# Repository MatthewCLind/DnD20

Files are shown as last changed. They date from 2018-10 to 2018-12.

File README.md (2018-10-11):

# DnD20
WiFi Connected electronic die for enhancing online DnD gameplaying

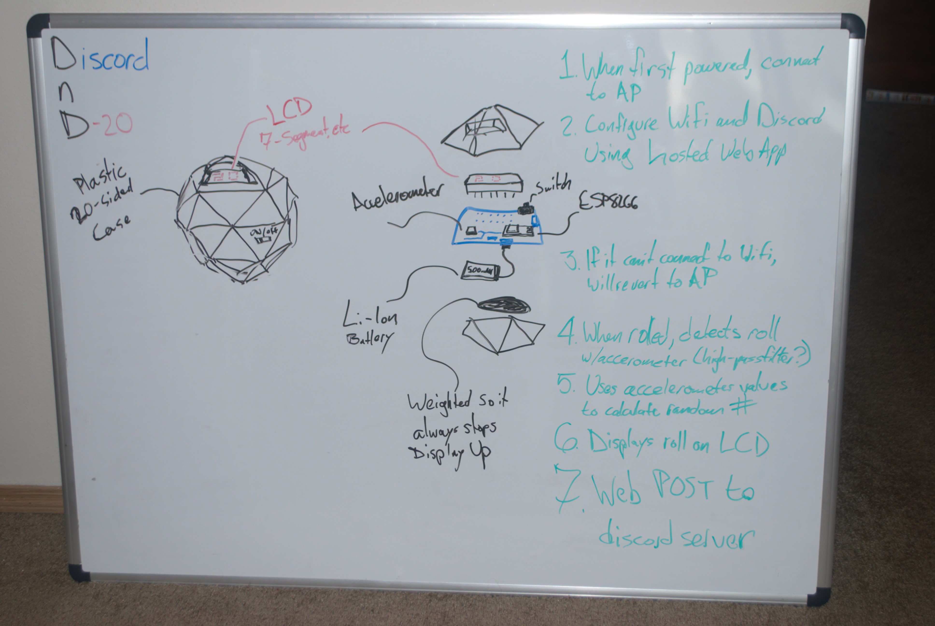
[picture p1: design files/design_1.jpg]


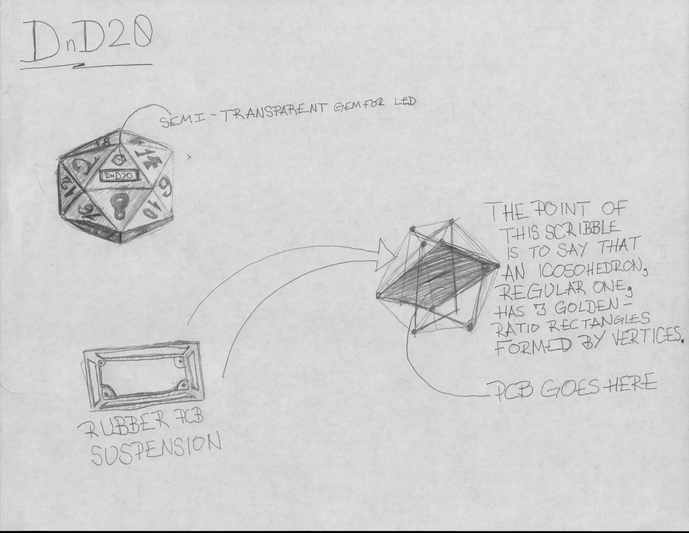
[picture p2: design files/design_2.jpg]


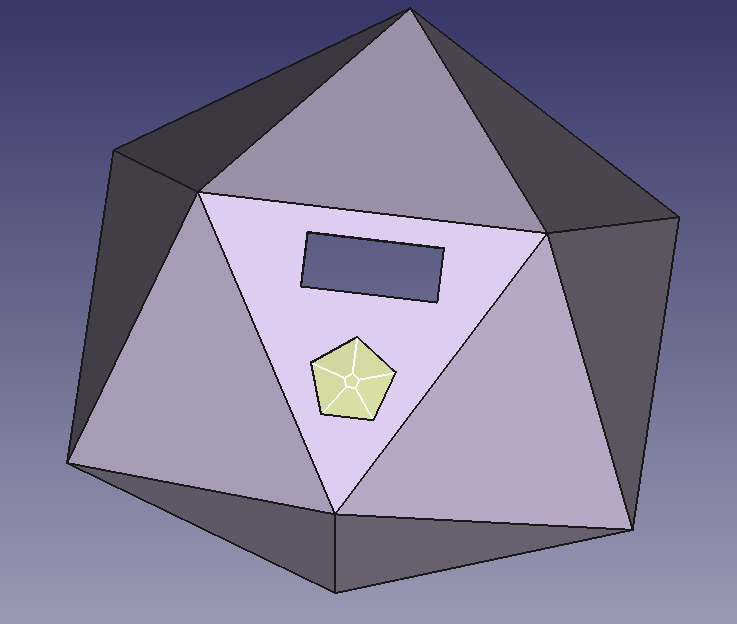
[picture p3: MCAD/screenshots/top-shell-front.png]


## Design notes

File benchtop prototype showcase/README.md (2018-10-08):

# Benchtop Prototype

**Rolling a Nat 20**

critical

### 1. Connect to WiFi

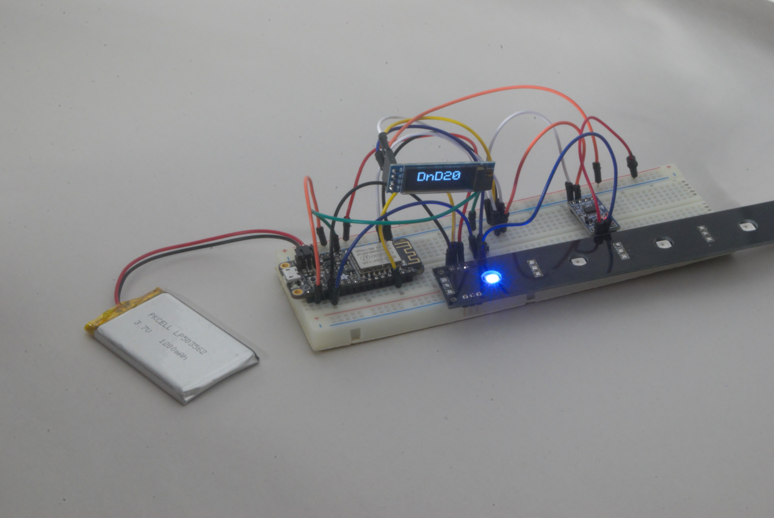
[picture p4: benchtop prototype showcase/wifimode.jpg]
wifi


When DnD20 first starts, the LED will be purple (it looks more purple IRL). This means that you are ready to enter in your WiFi credentials to get it logged on. 

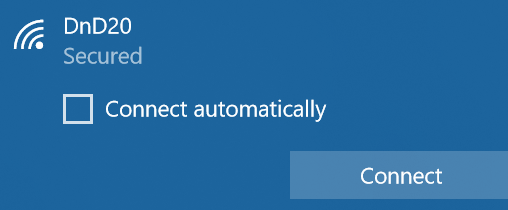
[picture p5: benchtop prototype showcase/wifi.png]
wifi


*the password is prestidigitation*

Alternatively, you can skip this step and start rolling without internet connection by pressing and holding the button.

In the future you'll be able to enter in your Discord server URL and a name for the bot, but for now you have to hardcode it in.

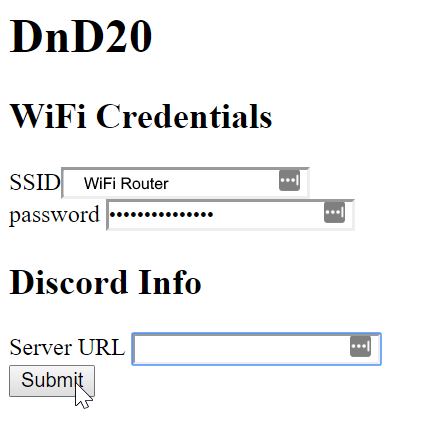
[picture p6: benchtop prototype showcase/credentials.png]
credentials


### 2. Start Rolling
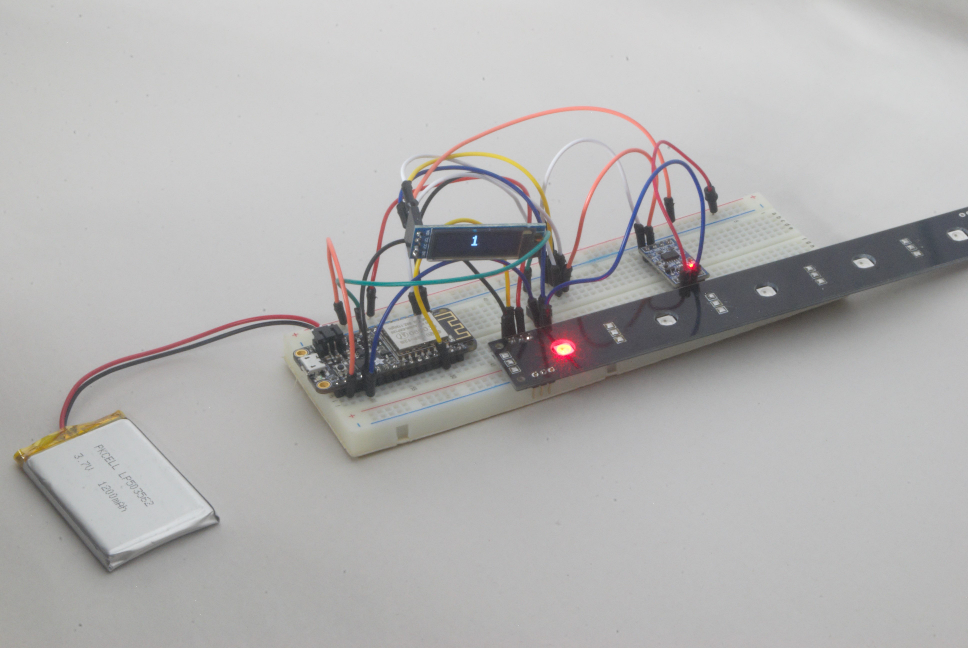
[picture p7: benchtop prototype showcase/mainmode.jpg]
failure


You can now start rolling a D20. Right now, rolling is simply tilting the device far enough toward the positive x direction for a moment. 

A Critical Failure turns the LED **red** in shame. A natural 20 turns the LED **gold** in triumph.

After rolling, there is a 10-second timeout so you can look at the device without re-rolling. To skip this, press the button momentarily.

If everything goes well with the WiFi setup and Discord webhook, and everything in-between, then your rolls should start showing up on your Discord server!

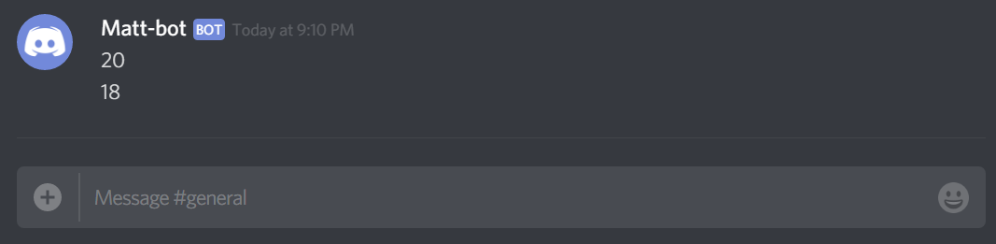
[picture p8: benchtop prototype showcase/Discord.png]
discord


### 3. Change the Die
program

While in the main rolling mode, you can change over to *Programming Mode* by pressing and holding the button.

In this mode, the LED turns green, and you can change the sidedness of the dice. So you can get anything from a d2 to a d20.

# What's Next?
Now that I've got everything working, at least when I'm lucky, it's time for improvements and upgrades.

### Code
The code is a mess. It is cobbled together. Re-organizing will help readability. I will also considering moving chunks to their own files.

The other most important thing is to get stability to the code. The ESP8266 still restarts occasionally, and has trouble advancing into the "normal mode". This has something to do with giving CPU time over to the WiFi duties by calling yield(). There may also be some strange conflicts in the libraries I'm using, since some of them are shared by multiple classes.

### Mechanical
I want to design the shell for this device. It will obviously be a d20. I'm imagining it in 2 halves. Where they come together will be a spot for the PCB. The button and power switch don't necessarily need to come off of the PCB itself, but can be attached with wires and be screwed into the side of the shell.

One thing I'm curious about is the placement of the accelerometer. It can either go near the middle or near the outside. Near the outside seems like it would hit the highest peak forces. The highest-acceleration would be from gravity and centripetal acceleration as the device rolls.

Placing the accelerometer in the center means that centripetal force is negligible. So all of the forces are from gravity only, and we'll just see the force vector moving around at a more constant magnitude. This might simplify the analysis it takes to determine a legitimate roll.

One more thing on the mechanical side. I was thinking the PCB might be put on rubber standoffs. I imagine a rubber net of sorts. The advantage to this is it acts like a low-pass filter. The device is going to be thrown on a table which will generate sharp peaks of force that could be a problem.

### Electronics
The next step here is to design a PCB. I mean, I could solder it up, but PCBs are so much nicer and more fun. The schematic can be done right away. The most uncertain part for me is the accelerometer board. The ESP8266 is an Adafruit Huzzah Feather board, so I can use their schematic to figure stuff out. The LED is a WS2812, which only needs a capacitor and maybe a resistor. As for the OLED, I'll probably just stick with the current screen.

I'm going to use this project as an opportunity to use the FreeCAD Stepup plugin to generate a board layer from an mCAD file.

### Functionality

**Programming Mode**
* I want to combine the WiFi setup with the program mode, it makes more sense to have a single programming mode
* Then, I want to have the Web App always hosted in programming mode. It will be accessible through the hosted Access Point if the WiFi isn't setup, or through the local network if it is connected
* The Web App will have more features, like being able to set the sidedness of the die, changing the Bot name, and the Discord server

**Magic 8-Ball**
* This thing is just asking to become a magic 8 ball, so I'll oblige
* Will be selectable through the web-app, or through some sort of button press, maybe holding for longer

**Button & LED**
* Right now you have to count in your head, then add some, to make sure you've held the button down long enough
* Instead, the LED should change colors once you've held the button down long enough, so you know you can let go. This also enables the use of holding down for long periods to cycle through several different options

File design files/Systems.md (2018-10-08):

/pulled from captain's log stardate-12018.10.4/

# Power
- li-ion battery powered
- needs to last 10 hours (5 hours of gameplay, plus 5 hours of "oops I forgot to charge this")
- On/Off switch to save power
- USB rechargeable
- Display
- Displays up to 99 (IE 2 digits)
- Backlit
- RGB LED
- Flashes heroically when a nat 20 is rolled
- Lights up triumphantly when denatured 20 is rolled
- Burns with sorrow when a critical failure is rolled

# Button Input
- One push button to cycle through type of die
- Push + hold for 3 seconds to enter programming mode
- Set it to D2, D3, ... , D99
- Display shows die type at boot

# Accelerometer
- Determines between roll and simply being moved about
    - How?
    - Band-pass filter?
    - Magnitude of force-vector?
    - Conic-volume traced out by force-vector > some amount?
    - Area of surface traced out by force-vector?
- Provides data to create random number

# WiFi
- At first provides access point for configuration
    * Ideally captive access point
    * Configuration = wifi credentials, Discord server config
- If wifi router access is unobtainable reverts to being an AP

# FUTURE DEV
 - Could interface with online DnD character sheets
 - so you can "roll attack" and it will actually calculate for you
- E.G. interface with Roll20 and OrcPub
- Interface ought to be simple and universal. So in the WiFi config, you simply specify an URL to POST the json with data
- Also accepts json to know what type of die to roll and what modifiers to put on it
- Bluetooth would also be nice so it can have a native phone app that interfaces for easy selection

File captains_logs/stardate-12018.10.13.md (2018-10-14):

# DnD20 - Oct 13 2018

* Magic 8 ball works
* More webapp options

**I learned something amazing!**
Apparently the ESP8266 remembers your network credentials. I was messing around with the device after having it powered off for over an hour, and it started posting to Discord. Interesting stuff. I wonder if there is a way to access that info?

## Firmware Update
* I've combined the wifi mode into the progmode, it just makes more sense
* I've also added in magic 8 ball functionality
* I've updated the web app to accomodate the 8 ball, and changed it to allow a bot name
* I need to make it so that you can re-enter the wifi mode again. right now, it is dependent on password == "" && ssid == "". So once you set those, you never start the AP again

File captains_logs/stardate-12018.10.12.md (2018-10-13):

# DnD20 - Oct 12 2018

* Created SVG file for laser cutting a fancy prototype
* I'll solder together my breadboard version to a perf board so it fits

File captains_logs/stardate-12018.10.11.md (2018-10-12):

# DnD20 - Oct 11 2018

* Schematic done and PCB started

## Schematic Work

* Starting with another project, which basically duplicated the Adafruit Feather Huzzah, I have started on the schematic
* I noticed that the WS2812 data line is also on the RX line, where the USB programming data comes in, which is why the LED changes colors while it is being programmed. I wonder if there is a good way to separate the two?
* **Oh No!** The MMA7455 accelerometer is obsolete D:
    * I found this one: http://cache.freescale.com/files/sensors/doc/data_sheet/MMA8653FC.pdf
    * I'm going to just move forward with this, because odds are the i2c is similar, but even if it isn't 1-to-1, I know that there is *some* way to interface with it. I'm ok with a theoretically working circuit right now, since my main goal is to get an entire project wrapped up

### MMA8653 Notes
* Perfect, the MMA8653FC already has a schematic symbol in KiCAD :)
* Interesting, there is mention of a "Freefall" interrupt, which is probably what the INT pins are for. That might be a good thing to implement, that way there is the option of using the INT pins, and maybe detecting a freefall is the best possible way to ensure a roll?
    * Check under section 6.7 for more info
* Tentatively attaching INT1 and INT2 on the MMA to the ESP12 GPIO10 and GPIO09
    * look at this for more pin info (pinfo) https://www.esp8266.com/wiki/doku.php?id=esp8266_gpio_pin_allocations#interrupts

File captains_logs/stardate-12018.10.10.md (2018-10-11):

# DnD20 - Oct 10 2018

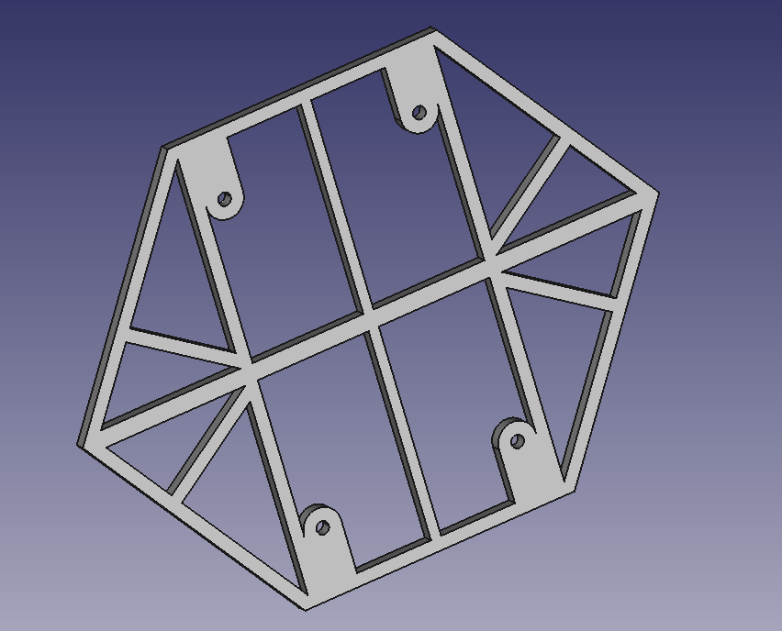
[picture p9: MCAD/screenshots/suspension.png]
suspension


* I got the rubber suspension part modeled in FreeCAD
* Also made a PCB model based off of that
* Then I saved the PCB model as a .step, which I converted to a .dxf using the KiCAD stepup plugin
* In KiCAD, I created a new project, and imported the .dxf PCB outline into the .pcb file, so now I'm ready to rock and roll on the electronics design

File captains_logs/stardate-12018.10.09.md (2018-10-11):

# DnD20 - Oct 9 2018

* To model a regular icosohedron in FreeCAD, what you do is make 3 perpendicular golden rectangles, then connect their corners with edges.

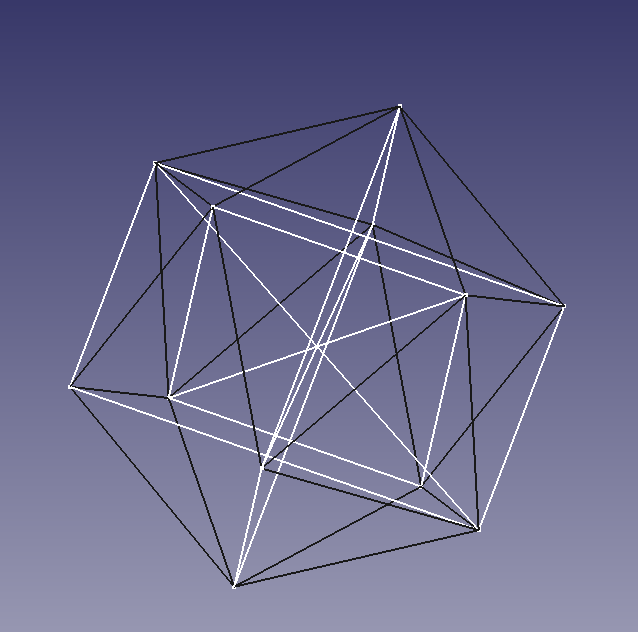
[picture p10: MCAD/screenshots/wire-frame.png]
Golden Rectangles


* Then you turn the edges into faces, the faces into a shell, and the shell into a solid
* To hollow out your solid, you can duplicate it and use the Draft toolbar to scale the solid down. This gives you the inner solid to do a boolean cut with

I think later this week I'll make a cardboard prototype so that I have the actual physical device put together. That way I can save off some of the accelerometer data and see what it looks like while rolled, too.

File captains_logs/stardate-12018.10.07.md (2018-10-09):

# DnD20 - Oct 7 2018

*edit: this story has a happy ending*

Last night I was thinking about how there are two different configuration modes. There's the mode where you can select the die sidedness, and the mode where you set up wifi. I think these should be combined. Whenever you enter into *The* configuration mode, you will launch the wifi AP (btw, in the future the website should be made available on your wireless network once the credentials are put in).

Furthermore, I was thinking that this device is perfectly suited to be a magic 8 ball. It would be easy enough to choose which type of device you want in the web app using a radio button. Better would be a separate page for each device type, with configuration options, and you can choose and save.

Another improvement to make is to have the button press & hold functionality display a color change on the LED once you've held it down long enough to switch to a new mode.

## Accelerometer Notes
* Using this code [MMA7455](https://playground.arduino.cc/Main/MMA7455)
* I'm thinking that I will combine the 3 axes into a single magnitude value, but then again maybe not
* Noticing a lot of values sporadically of 65535 with the accelerometer simply staying put on the table
    * This is the 16 bit max value, so that is dubious
    * Ah, so it consistently switches back and forth when I rock the accelerometer. These must be negative numbers, let me see if I can find an unsigned int somewhere and make it signed.
    * In the loop() I cast the x,y,z values to int_16t in the print statements, now it looks nicer
* Because I'm having no immediate luck with FFT, I'm just going to wrap up this part of the prototype by considering a "roll" to be holding it at a high enough inclination

## Other improvements
* Added a timeout after the roll
* Made it so you can skip the timeout if you are ready to roll again

## HTTP Request notes
* To figure out how the headings are supposed to be set up, I'm going to CURL [HTTPBIN](http://httpbin.org/)
* I've succesfully sent a CURL request to my Discord server, so I'll duplicate that @ HTTPBIN
* Then I'll get my ESP8266 code to match, and it should be able to send the right stuff to Discord
* CURL info: [birdie0 discord webhooks](https://birdie0.github.io/discord-webhooks-guide/tools/curl.html)
* This works for me @ discord:
    * ` curl -H "Content-type: application/json" -X POST -d '{"username": "ROBOTO", "content": "content of content"}'https://discordapp.com/api/webhooks/####/##### `
    
* Here's what I get back from @ HTTPBIN:

``` HTML
<!DOCTYPE HTML PUBLIC "-//W3C//DTD HTML 3.2 Final//EN">
<title>405 Method Not Allowed</title>
<h1>Method Not Allowed</h1>
<p>The method is not allowed for the requested URL.</p>
``` 

* possibly because it doesn't want JSON data? or is it the POST?
* it was the post and the URL

* second try:
``` Javascript
{
  "headers": {
    "Accept": "*/*",
    "Connection": "close",
    "Content-Length": "56",
    "Content-Type": "application/json",
    "Host": "httpbin.org",
    "User-Agent": "curl/7.52.1"
  }
} 
```

* Hitting some issues with I2C dropping after going through the WiFi routine
    * This only occurs if I hardcode in my router credentials and start immediately into client mode
    
* This is what I get back from HTTPBIN:
``` 
HTTP/1.1 400 Bad Request
Connection: close
Server: Cowboy
Date: Mon, 08 Oct 2018 00:50:32 GMT
Content-Length: 0 
```

* This is what my code looks like:
* NOTE: discord_server = "/headers"

``` C++
void send_http_request(int roll)
{
  // Use WiFiClient class to create TCP connections
  WiFiClient client;
  const int httpPort = 80;
  if (!client.connect("httpbin.org", httpPort)) {
    Serial.println("connection failed");
    return;
  }

  // This will send the request to the server
  client.print(String("GET ") + discord_server + " HTTP/1.1\r\n" + 
                "Host: httpbin.org" + "\r\n" +
                "Content-Type: application/json\r\n" +
               "Connection: close\r\n" +
               player_name + " rolled: " +
               roll +
               "\r\n\r\n");
  unsigned long timeout = millis();
  while (client.available() == 0) {
    if (millis() - timeout > 5000) {
      Serial.println(">>> Client Timeout !");
      client.stop();
      return;
    }
  }
  
  // Read all the lines of the reply from server and print them to Serial
  while(client.available()){
    String line = client.readStringUntil('\r');
    Serial.print(line);
  }
} 
```
* The payload wasn't in JSON format, maybe that is the issue? Yes.

* I'm getting 302 errord (FOUND). I'm pretty sure it is because I'm trying HTTP and not HTTPS
* In case you were wondering, you can't simply change the HTTP/1.1 to HTTPS/1.1 ... 
     * No, no. Haha, no wrong of course not. That would be too easy.
     * The *real* way to do it is to change ` WifiClient client` to `WifiClientSecure client `. Sophisticated. Refined.
     * Ah, shoot. Don't forget to change the library #include statement too
     * Well I don't know, it crashes.

* Attempting to use the ESP8266 example, "HTTPSRequest"
* Lots of fiddling, no 100% success yet
* Another note on CURL: use -v to see the headers
* It looks like the issue is that the server isn't reading the data as json data

# **SUCCESS!!!!!**
**Every single piece piece of functionality now works together!**

* After fiddling around getting all of the carriage returns and newlines right in the data, I also managed to get the JSON format right haha
* Using the HTTPSRequest example code I was able to send a message to my Discord server :D
* The reason it was crashing is because I was re-initializing my initialized devices (LED, OLED, Accelerometer)

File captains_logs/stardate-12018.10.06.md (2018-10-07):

# DnD20 - Oct 6 2018

## Update
* OLED working, displays rolls
* RGB LED working
* WiFi AP starts and accepts input from html form
    * SSID
	* password
	* discord-server info
* Learned that calling yield() is important for ESP8266
* Made a webhook on my Discord Server
    * successfully posted to it using CURL
	* having issues getting ESP8266 to POST, probably an issue with my http header
* Have hooked up the acceleromter, but haven't ported code into dnd20 firmware

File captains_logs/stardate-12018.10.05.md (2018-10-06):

# DnD20 - Oct 5 2018

I have gotten a good start on the firmware for my prototype. I started by looking at the Arduino Examples for all of the systems I needed - ESP8266 WiFi, Makuna NeoPixel, MMA7455, etc. I foolishly tried combining all of the examples into a single file as if the way to construct a house is to start by unloading a pile of lumber into a heap on the ground. Learn from my mistakes folks, start with a blank, pristine file :)

I followed my state(less?) pattern that I outlined in this youtube video: https://youtu.be/jQ43RBiS8FQ

At this point I have the main framework down. One advantage of having all functionality lumped into strict states is that you can add in dummy code as a placeholder for functionality. Rather than implementing the OLED code right away, since it takes time, I've got a placeholder using the Serial port.

I also got a start on the webpage. I want to keep this as small (memory-wise) as possible for now, since I'm not sure how much the rest of the sketch is going to take.

The goal at this point is to a fully-functional prototype on a breadboard.

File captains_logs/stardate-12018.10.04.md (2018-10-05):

# DnD20 - Oct 4 2018
When playing DnD with your friends over the internet, some of the magic is lost. There's something about the latency and missing out on the dice rolling that limits DnD online. As for the dice, I think we can do something about that.

The idea here is to make an electronic die that can interface with your online session so that when you roll, your friends can watch the outcome with you in real time and cheer or jeer depending on the results (and their alignment).

Once you get an IoT die, there are lots more possibilities to include things like "fancy rolls" (tm) which allows you to specify what in the heck you are rolling for. I always forget what I need to add up when I decide to throw my axe rather than use it like a melee weapon. The die / app combo could all figure that out for me.

Yes, there's plenty of good possibilities here, but to start out, we need something that we can actually make.

My first pass at the systems' design looks like this:

# Power
- li-ion battery powered
- needs to last 10 hours (5 hours of gameplay, plus 5 hours of "oops I forgot to charge this")
- On/Off switch to save power
- USB rechargeable
- Display
- Displays up to 99 (IE 2 digits)
- Backlit
- RGB LED
- Flashes heroically when a nat 20 is rolled
- Lights up triumphantly when denatured 20 is rolled
- Burns with sorrow when a critical failure is rolled

# Button Input
- One push button to cycle through type of die
- Push + hold for 3 seconds to enter programming mode
- Set it to D2, D3, ... , D99
- Display shows die type at boot

# Accelerometer
- Determines between roll and simply being moved about
    - How?
    - Band-pass filter?
    - Magnitude of force-vector?
    - Conic-volume traced out by force-vector > some amount?
    - Area of surface traced out by force-vector?
- Provides data to create random number

# WiFi
- At first provides access point for configuration
    * Ideally captive access point
    * Configuration = wifi credentials, Discord server config
- If wifi router access is unobtainable reverts to being an AP

# FUTURE DEV
 - Could interface with online DnD character sheets
 - so you can "roll attack" and it will actually calculate for you
- E.G. interface with Roll20 and OrcPub
- Interface ought to be simple and universal. So in the WiFi config, you simply specify an URL to POST the json with data
- Also accepts json to know what type of die to roll and what modifiers to put on it
- Bluetooth would also be nice so it can have a native phone app that interfaces for easy selection

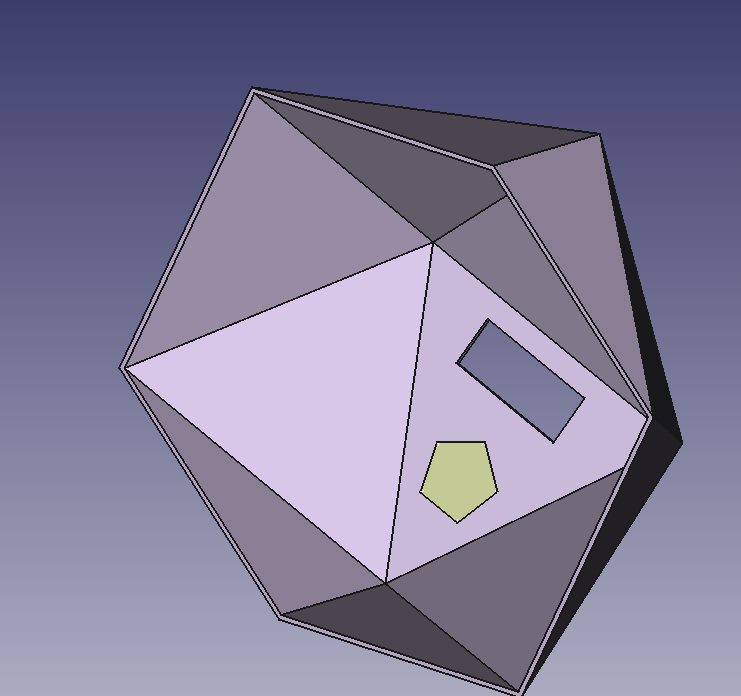
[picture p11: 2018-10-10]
MCAD/screenshots/top-shell-inside.png

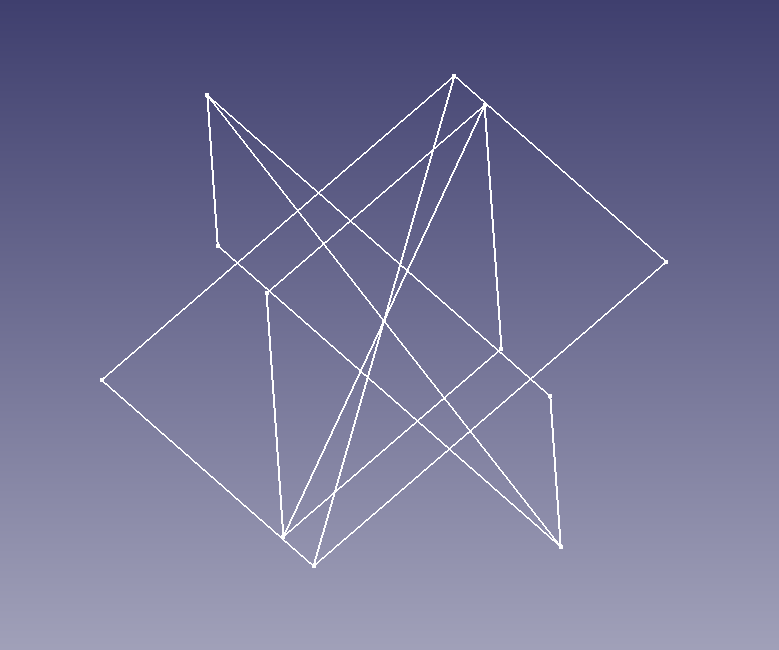
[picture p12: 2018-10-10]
MCAD/screenshots/golden_rect.png

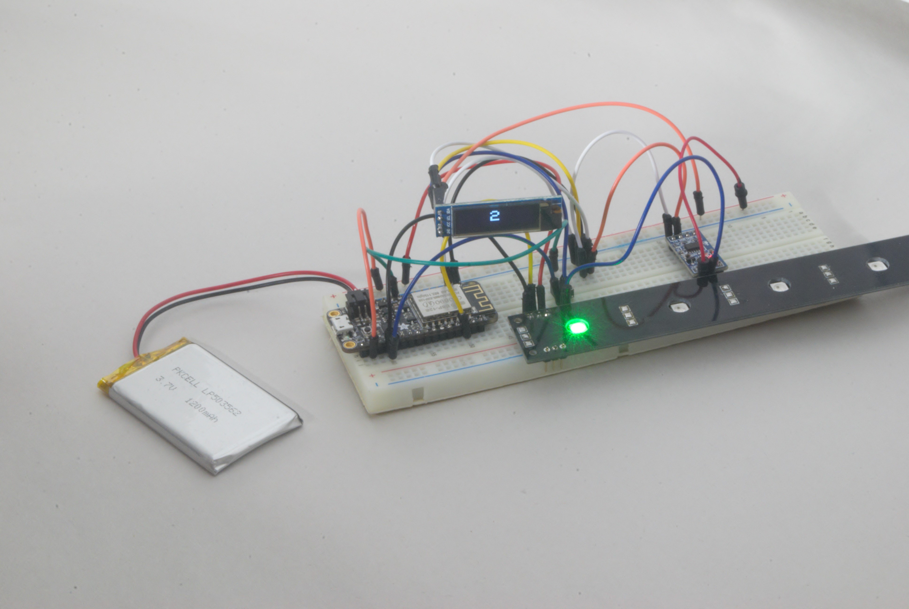
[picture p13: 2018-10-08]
benchtop prototype showcase/program_mode.jpg

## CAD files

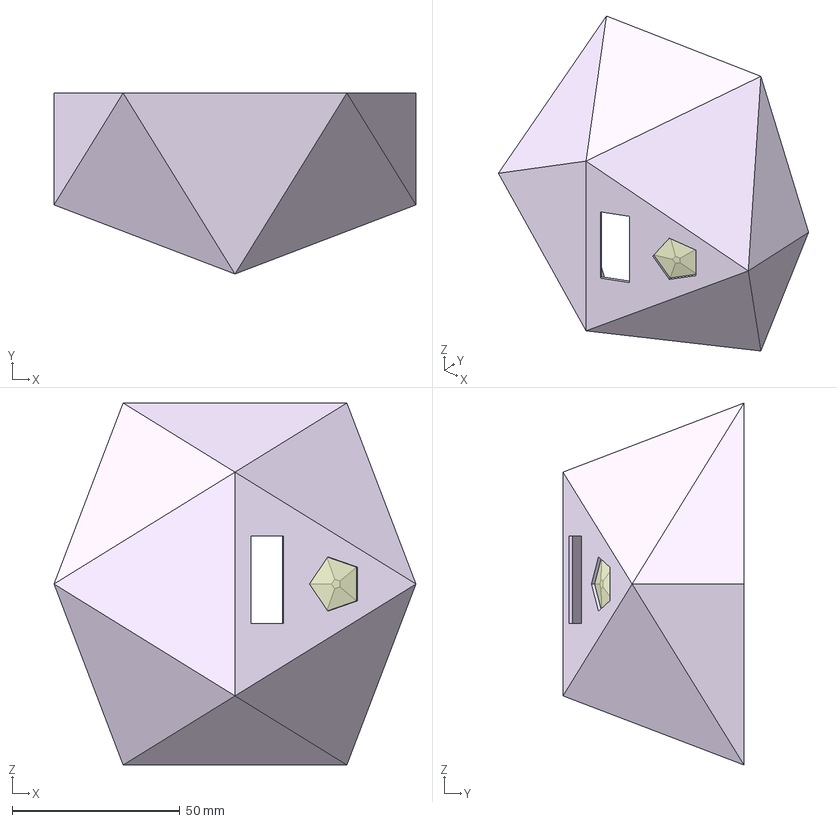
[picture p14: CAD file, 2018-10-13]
MCAD/freecad files/top_shell.fcstd
107.8 x 53.9 x 107.8 mm

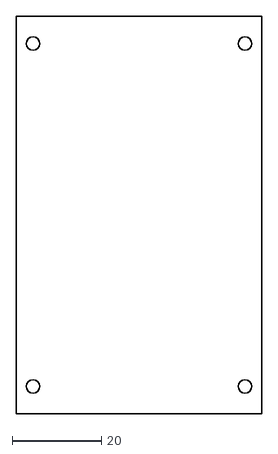
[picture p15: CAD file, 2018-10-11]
MCAD/freecad files/pcb_outline.dxf
55.0 x 89.0

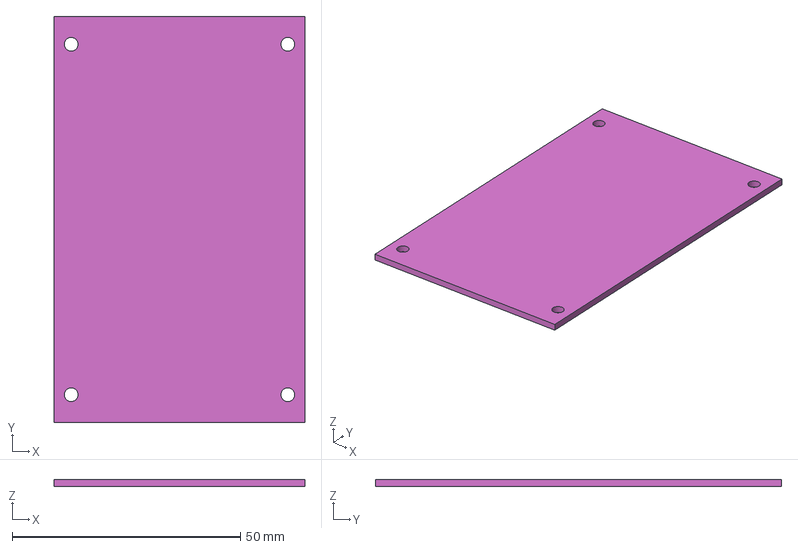
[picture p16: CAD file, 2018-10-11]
MCAD/freecad files/PCB.fcstd
55.0 x 89.0 x 1.60 mm

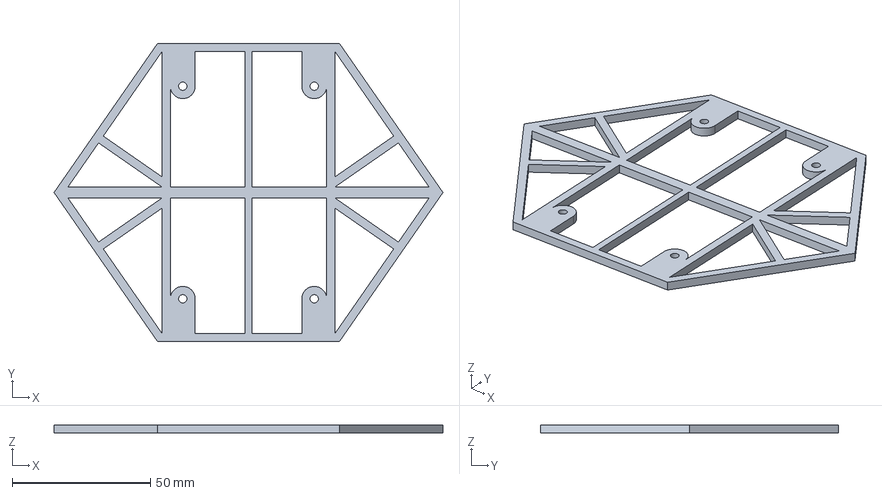
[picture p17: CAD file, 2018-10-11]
MCAD/freecad files/rubber_suspension.fcstd
140.4 x 107.8 x 3.00 mm

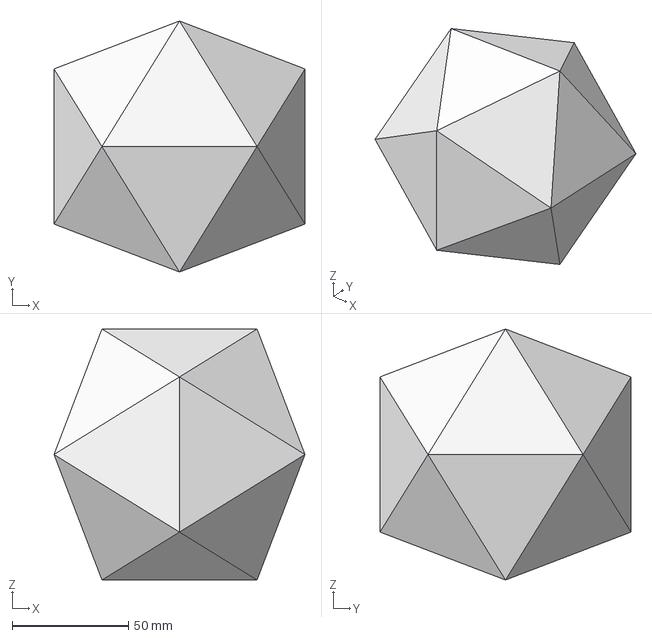
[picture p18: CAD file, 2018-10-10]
MCAD/freecad files/dnd20.fcstd
107.8 x 107.8 x 107.8 mm

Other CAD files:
MCAD/freecad files/dnd20_pcb.step
MCAD/freecad files/half-shell.fcstd

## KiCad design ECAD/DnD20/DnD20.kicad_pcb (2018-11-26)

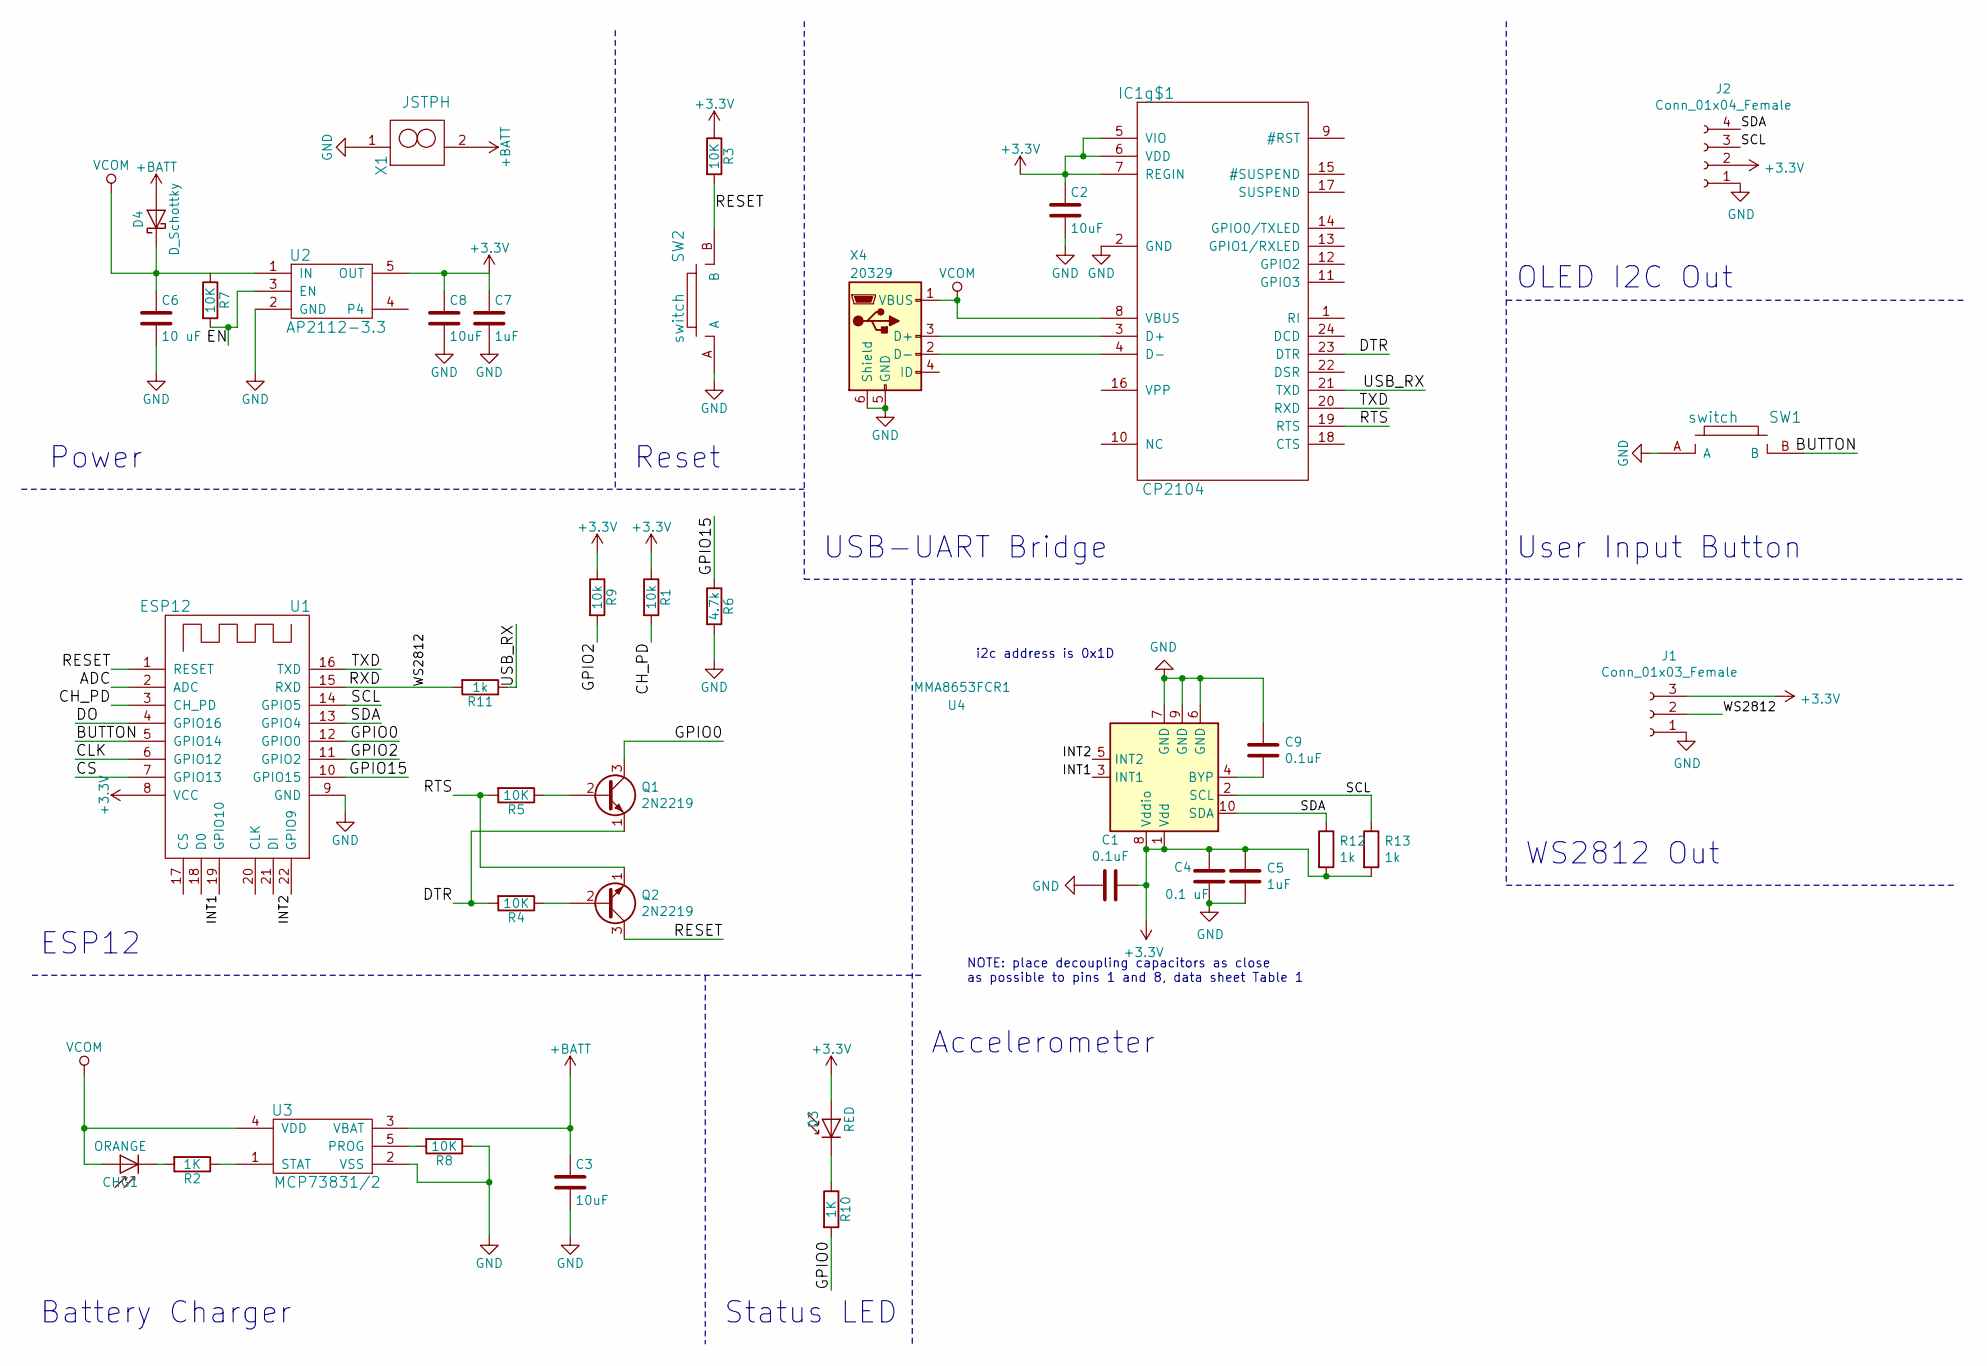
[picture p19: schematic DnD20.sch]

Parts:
C1, C9: 0.1uF; C_0805_2012Metric
C2, C3, C8: 10uF; C_0805_2012Metric
C4: 0.1 uF; C_0805_2012Metric
C5, C7: 1uF; C_0805_2012Metric
C6: 10 uF; C_0805_2012Metric
CHG1: ORANGE; LED_0603_1608Metric
D3: RED; LED_0603_1608Metric
D4: D_Schottky; D_T-1_P5.08mm_Horizontal
IC1g$1: CP2104; QFN-24-1EP_4x4mm_P0.5mm_EP2.7x2.7mm
J1: Conn_01x03_Female; PinHeader_1x03_P2.54mm_Vertical
J2: Conn_01x04_Female; PinHeader_1x04_P2.54mm_Vertical
Q1, Q2: 2N2219; TO-39-3
R1, R9: 10k; R_0805_2012Metric
R2, R10: 1K; R_0805_2012Metric
R3, R4, R5, R7, R8: 10K; R_0805_2012Metric
R6: 4.7k; R_0805_2012Metric
R11, R12, R13: 1k; R_0805_2012Metric
SW1, SW2: switch; clicky_button
U1: ESP12; ESP-12E_SMD
U2: AP2112-3.3; SOT-23-5_HandSoldering
U3: MCP73831/2; SOT-23-5_HandSoldering
U4: MMA8653FCR1; DFN-10_2x2mm_P0.4mm
X1: JSTPH; JST_PH_S2B-PH-K_1x02_P2.00mm_Horizontal
X4: 20329; USB_Micro-B_Wuerth_629105150521

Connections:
+3V3: C1.1, C2.1, C4.2, C5.1, C7.1, C8.1, D3.2 (A), IC1g$1.5 (VIO), IC1g$1.6 (VDD), IC1g$1.7 (REGIN), J1.3, J2.2, R1.1, R3.1, R9.1, R12.2, R13.2, U1.8 (VCC), U2.5 (OUT), U4.1 (Vdd), U4.8 (Vddio)
+BATT: C3.1, D4.2 (A), U3.3 (VBAT), X1.2
/ADC: U1.2 (ADC)
/BUTTON: SW1.B, U1.5 (GPIO14)
/CH_PD: R1.2, U1.3 (CH_PD)
/CLK: U1.6 (GPIO12)
/CS: U1.7 (GPIO13)
/DO: U1.4 (GPIO16)
/DTR: IC1g$1.23 (DTR), Q1.1 (E), R4.2
/EN: R7.2, U2.3 (EN)
/GPIO0: Q1.3 (C), R10.2, U1.12 (GPIO0)
/GPIO2: R9.2, U1.11 (GPIO2)
/GPIO15: R6.1, U1.10 (GPIO15)
/INT1: U1.19 (GPIO10), U4.3 (INT1)
/INT2: U1.22 (GPIO9), U4.5 (INT2)
/RESET: Q2.3 (C), R3.2, SW2.B, U1.1 (RESET)
/RTS: IC1g$1.19 (RTS), Q2.1 (E), R5.2
/RXD: J1.2, R11.2, U1.15 (RXD)
/SCL: J2.3, R13.1, U1.14 (GPIO5), U4.2 (SCL)
/SDA: J2.4, R12.1, U1.13 (GPIO4), U4.10 (SDA)
/TXD: IC1g$1.20 (RXD), U1.16 (TXD)
/USB_RX: IC1g$1.21 (TXD), R11.1
GND: C1.2, C2.2, C3.2, C4.1, C5.2, C6.2, C7.2, C8.2, C9.1, IC1g$1.2 (GND), J1.1, J2.1, R6.2, R8.1, SW1.A, SW2.A, U1.9 (GND), U2.2 (GND), U3.2 (VSS), U4.6 (GND), U4.7 (GND), U4.9 (GND), X1.1, X4.5 (GND), X4.6 (Shield)
unnamed: C9.2, U4.4 (BYP)
unnamed: CHG1.1 (K), R2.2
unnamed: D3.1 (K), R10.1
unnamed: IC1g$1.3 (D+), X4.3 (D+)
unnamed: IC1g$1.4 (D-), X4.2 (D-)
unnamed: Q1.2 (B), R5.1
unnamed: Q2.2 (B), R4.1
unnamed: R2.1, U3.1 (STAT)
unnamed: R8.2, U3.5 (PROG)
VCOM: C6.1, CHG1.2 (A), D4.1 (K), IC1g$1.8 (VBUS), U2.1 (IN), U3.4 (VDD), X4.1 (VBUS)

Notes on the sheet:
NOTE: place decoupling capacitors as close as possible to pins 1 and 8, data sheet Table 1
i2c address is 0x1D
Power
ESP12
Battery Charger
USB-UART Bridge
OLED I2C Out
User Input Button
WS2812 Out
Accelerometer
Reset
Status LED

Board: 2 copper layers, 38 parts (2 on the bottom side), 29 nets, no tracks yet.

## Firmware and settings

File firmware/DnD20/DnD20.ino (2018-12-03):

/*
 * DnD20
 * Author: Matthew Lind
 * last revision: 11/23/2018
 * 
 * License: This code is public domain but you buy me a beer if you use this and we meet someday (Beerware license).
 * 
 * Overview:
 * DnD20 overall is a device for sharing your dice rolls online through Discord.
 * If you want to set this device up, you'll need to create a Webhook on your Discord server.
 * 
 * Organization:
 * DnD20.h holds all of the declarations. Arduino will stitch all of these files together
 *  when compiled. They are split up for convenience only, so DnD20.h allows the files
 *  to "be on the same page". Get it?
 * DnD20.ino is the main file where the 3 modes live, Game Mode, Game Setup, and WiFi Setup.
 * Devices.ino is for device-level functions.
 * EEPROM_Management.ino is functions to save and load configuration data
 * WiFi.ino handles the Access Point and HTTP Client code
 * 
 * 
 * Sources:
 * https://github.com/Makuna/NeoPixelBus
 * https://github.com/adafruit/Adafruit_SSD1306
 */

#include "DnD20.h"


/*
 * Game Mode is the main mode of the device.
 * Depending on configuration, the device will act as a:
 *  - D20, D12, D10, D8, D6, or D4
 *   or
 *  - a Magic 8 Ball
 * Only the dice send HTTP POSTs to discord (if connected to WiFi)
 */
void game_mode()
{ 
  // game_mode setup block
  if(device_state.run_mode_setup)
  {
    if(WiFi.status() != WL_CONNECTED)
    {
      start_WiFi_client();
    }
    if(device_state.game_type == MAGIC_8)
    {
      set_neopixel_color(colors.purple);
    }
    display_mode(device_state.mode);
    device_state.run_mode_setup = false;
  }

  bool button_click;
  device_state.mode = button_mode_select(&button_click);

  if(button_click)
  {    
    // blink the LED to separate identical rolls
    set_neopixel_color(colors.black);
    
    delay(100);
    // make the random generator more random
    int seed = millis();
    randomSeed(seed);
    device_state.roll = (int)random(device_state.die_sidedness) + 1;
    
    if(device_state.game_type == D20)
    {
      update_OLED(String(device_state.roll));
      
      // update the LED
      if(device_state.roll == device_state.die_sidedness)
      {
        set_neopixel_color(colors.yellow);
      }
      else if(device_state.roll == 1)
      {
        set_neopixel_color(colors.red);
      }
      else
      {
        set_neopixel_color(colors.blue);
      }
  
      // send HTTP POST to Discord Server
      if(WiFi.status() == WL_CONNECTED)
      {
        send_discord_http_request(device_state.roll);
      }
    }
    else if(device_state.game_type == MAGIC_8)
    {
      const String RESPONSES[] = 
      {"Certainly", "Mmhmm", "No doubt", "Yes", "Do it", "Probly",
       "Most      likely", "Sure", "Yep", "For sure", "Ummm", "Ask later", "Can't say", "Dunno", "What?", "No", "No way",
       "Probly not", "Nuh-uh", "Doubt it"};

       update_OLED(RESPONSES[device_state.roll - 1]);
       set_neopixel_color(colors.purple);
    }

    delay(20); // avoid button jitter
  }

  if(device_state.mode != GAME_MODE)
  {
    set_neopixel_color(colors.black);
    update_OLED("");
    device_state.run_mode_setup = true;
  }
}


/*
 * Game Setup is the mode where you can cycle through different dice,
 * or set it to be a Magic 8 Ball
 * 
 * To cycle to different modes, press and hold the button
 */
void game_setup()
{
  const int MAX_SIDEDNESS = 20;

  if(device_state.run_mode_setup)
  {
    set_neopixel_color(colors.green);
    display_mode(device_state.mode);
    device_state.run_mode_setup = false;
  }

  bool button_click;
  device_state.mode = button_mode_select(&button_click);
  
  //button click to scroll through the different dice / game types
  if(button_click)
  {
    if(device_state.game_type == D20)
    {
      const int num_dice = 6;
      const int dice_types[num_dice] = {4, 6, 8, 10, 12, 20};
      int current_die_index = 0;
      Serial.println(device_state.die_sidedness);
      for(int i = 0; i < num_dice; i++)
      {
        if(device_state.die_sidedness == dice_types[i])
        {
          current_die_index = i;
          break;
        }
      }
      current_die_index--;
      
      if(current_die_index < 0)
      {
        device_state.die_sidedness = 20;
        device_state.game_type = MAGIC_8;
        update_OLED(String("Magic     8 Ball"));
      }
      else
      {
        device_state.die_sidedness = dice_types[current_die_index];
        display_dN(device_state.die_sidedness);
      }
    }
    else // game type == Magic 8 Ball, cycle back to D20
    {
      device_state.game_type = D20;
      device_state.die_sidedness = 20;
      display_dN(device_state.die_sidedness);
    }

    delay(20); // avoid button jitter
  }

  // set up for the next mode
  if(device_state.mode != GAME_SETUP)
  {
    set_neopixel_color(colors.black);
    update_OLED("");
    device_state.run_mode_setup = true;
    EEPROM_save_data();
  }
}

/*
 * WiFi setup hosts an access point that you can log onto with a browser
 *  SSID: D20
 *  Password: prestidigitation
 *  
 * Once in this mode, the OLED will display whatever IP address you should connect to
 * Upon connecting, you will be served a web page to put in your Discord and WiFi credentials
 */
void wifi_setup()
{
  if(device_state.run_mode_setup)
  {
    start_server();
    set_neopixel_color(colors.orange);
    device_state.run_mode_setup = false;
  }

  server.handleClient();
  device_state.mode = button_mode_select();

  // set up for the next mode
  if(device_state.mode != WIFI_SETUP)
  {
    shutdown_server();
    set_neopixel_color(colors.black);
    update_OLED("");
    device_state.run_mode_setup = true;
    EEPROM_save_data();
  }
}


void setup()
{
  Serial.begin(115200);
  Serial.println("Setup Begin");
  
  device_state.run_mode_setup = true;
  device_state.roll = 1; //critical failure :(
  EEPROM_map_init();
  EEPROM_load_data();

  // Button
  pinMode(BUTTON_PIN, INPUT_PULLUP);
  
  // OLED
  display.begin(SSD1306_SWITCHCAPVCC, 0x3C);
  display.clearDisplay();
  display.setTextColor(WHITE);
  display.display();

  // NeoPixel
  colors.red    = RgbColor(66,  0,  0);
  colors.green  = RgbColor( 0, 66,  0);
  colors.blue   = RgbColor( 0,  0, 66);
  colors.yellow = RgbColor(33, 33,  0);
  colors.orange = RgbColor(44, 22,  0);
  colors.purple = RgbColor(16,  0, 33);
  colors.white  = RgbColor(33, 16, 16);
  colors.black  = RgbColor( 0,  0,  0);
  neopixel.Begin();
  neopixel.Show();

  // OLED
  Adafruit_SSD1306 display(16);
}

void loop()
{ 
  DnD20_Modes[device_state.mode]();
  
  // must give time for WiFi functions to avoid watchdog timer
  yield();
}

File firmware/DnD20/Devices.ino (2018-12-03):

// ----------------------------------
//            NeoPixel
// ----------------------------------

// change the neopixel to a pre-defined color
void set_neopixel_color(RgbColor c)
{
  for(int i = 0; i < NUM_NEOPIXELS; i++)
  {
    neopixel.SetPixelColor(i, c);
  }
  neopixel.Show();
}


// ----------------------------------
//               OLED
// ----------------------------------

// write something to the OLED,
// the text will be resized based on the number of characters
void update_OLED(String value)
{
  //             font sizes  1   2   3   4
  const int char_width[]  = {6, 12, 18, 24};
  const int char_height[] = {8, 16, 24, 32};

  // maximum number of characters at font 1 = 84
  int num_chars = (value.length() < 84) ? value.length() : 84;
  int font_size;
  int x_offset = 0;
  int y_offset = 0;

  if(num_chars <= 5)
  {
    font_size = 4;

    y_offset = (32 - char_height[3]) / 2;
    x_offset = (128 - (char_width[3] * num_chars)) / 2;
  }
  else if(num_chars <= 7)
  {
    font_size = 3;
    
    y_offset = (32 - char_height[2]) / 2;
    x_offset = (128 - (char_width[2] * num_chars))/2;
  }
  else if(num_chars <= 20)  // size 2 accomodates 2 rows of 10 chars
  {
    font_size = 2;
    
    x_offset = (num_chars <= 10) ? (128 - (char_width[1] * num_chars))/2 : 0;
    
    int rows = (num_chars <= 10) ? 1 : 2;
    y_offset = (32 - (char_height[1] * rows)) / 2;
  }
  else
  {
    int max_columns = 21;
    font_size = 1;
    x_offset = (num_chars <= 21) ? (128 - (char_width[0] * num_chars))/2 : 0;
    
    int rows;
    if(num_chars <= max_columns)
    {
      rows = 1;
    }
    else if(num_chars <= 2*max_columns)
    {
      rows = 2;
    }
    else if(num_chars <= 3*max_columns)
    {
      rows = 3;
    }
    else if(num_chars <= 4*max_columns)
    {
      rows = 4;
    }
    y_offset = (32 - (char_height[0] * rows)) / 2;
  }
  
  display.clearDisplay();
  display.setTextSize(font_size);
  display.setCursor(x_offset, y_offset);
  display.println(value);
  display.display();
}

// display a die type on the OLED
void display_dN(int N)
{
  String die_type = "d";
  die_type.concat(N);
  update_OLED(die_type);
}

void display_mode(int zmode)
{
  String display_string = mode_display_strings[zmode];
  update_OLED(display_string);
}

// ----------------------------------
//             Button
// ----------------------------------

// cycle through the modes, 
// button_press will be set to true if the button was only clicked
int button_mode_select(bool* button_press)
{
  *button_press = false;
  bool mode_change = false;
  int next_mode = device_state.mode;
  long start_time = millis();
  int elapsed_time;
  
  while(digitalRead(BUTTON_PIN) == LOW)
  {
    elapsed_time = millis() - start_time;
    if(elapsed_time > 1500)
    {
      mode_change = true;
      next_mode++;
      next_mode = next_mode % NUM_MODES;
      String display_string = mode_display_strings[next_mode];
      update_OLED(display_string);
      start_time = millis(); // so you can continue to cycle through
    }
    yield();
  }

  if(!mode_change && elapsed_time > 10 && elapsed_time < 1000)
  {
    *button_press = true;
  }

  return next_mode;
}

// cycle through the button modes
int button_mode_select()
{
  int next_mode = device_state.mode;
  long start_time = millis();
  int elapsed_time;
  
  while(digitalRead(BUTTON_PIN) == LOW)
  {
    elapsed_time = millis() - start_time;
    if(elapsed_time > 1500)
    {
      next_mode++;
      next_mode = next_mode % NUM_MODES;
      display_mode(next_mode);
      start_time = millis(); // so you can continue to cycle through
    }
    yield();
  }

  return next_mode;
}

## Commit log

2018-10-05 added LED feature
2018-10-05 added LEDs and fixedcompiler errors
2018-10-08 accelerometer, https request
2018-10-08 removed redundant device initalisor
2018-10-08 added Benchtop Prototype showcase
2018-10-10 adding MCAD files
    [dnd20.fcstd, half-shell.fcstd, top_shell.fcstd]
2018-10-11 created rubber suspension and PCB
    [PCB.fcstd, dnd20_pcb.step, rubber_suspension.fcstd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]
2018-10-11 created kicad, pcb outline, captains log
    [DnD20.kicad_pcb, DnD20.sch, pcb_outline.dxf]
2018-10-12 PCB schematic, board, and captains log
    [DnD20.kicad_pcb, DnD20.sch, top_shell.fcstd]
2018-10-13 created shell.svg
    [top_shell.fcstd]
2018-11-26 Refactored firmware before removing accelerometer
    [DnD20.kicad_pcb, DnD20.sch]
2018-11-29 3 modes. no push-button. not working
    [Devices.ino, DnD20.ino, EEPROM_Management.ino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]
2018-12-03 functional EEPROM, button, OLED, neopixel, wifi
